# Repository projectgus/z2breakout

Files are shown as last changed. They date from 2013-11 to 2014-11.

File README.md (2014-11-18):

**This is an abandoned alpha-quality design at this point, unless someone wants to pick it up. I built some prototypes in late 2013 and the USB connector & boost converter are verified, but there's some [known problems with the connector pinout](https://github.com/projectgus/z2breakout/issues/1) and the silkscreen is also pretty messy, the whole board probably needs to grow for more labelling space.**

## Z2 Breakout module

A breakout board for the "ZipIt Z2" dock connector. Alpha-quality at the moment.

Design files created with Kicad 2013-Mar-13-testing (this version or newer is probably required.)

Breaks out dock connector to provide:
* USB A & USB Micro B connectors (only one can be used at a time.)
* Camera header for a OV7670 camera module (untested), doubles as GPIO header.
* Dedicated i2c header with 3.3V power pins
* Other breakout headers for power, onboard "headphone remote" ADC, microphone input, "BTRXD" UART pin.
* PCB contains area to build a 3.3V -> 5V boost converter based on TI TPS61240, which can be jumpered to the USB A connector. This is so the USB A connector can be used when the ZipIt is running on battery.

NB: The 3.3V power supply in the ZipIt does not contain enough capacity to output 500mA @ 5V. (If you've measured the surplus current capacity of the 3.3V supply, please let me know and I'll post it here!)

Z2 Breakout design is Copyright (C) 2013 Angus Gratton, released under the TAPR OHL as described in the included file "LICENSE".

Comes with absolutely no warranty, may not work, etc. Not endorsed by or otherwise related to the company ZipIt Wireless.

# Known Issues

* Libraries are a bit of a mess, lots of piecemeal .mod files. Due for a cleanup.

* Did I mention it hasn't been successfully made or used yet? Good. :)

# Resources

Based on the excellent research done by other Z2 owners, and the information [released by ZipIt Wireless themselves](http://linux.zipitwireless.com/):

* http://bealecorner.org/best/measure/z2/z2-connector-pinout-2011.txt

* http://embeddedprogrammer.blogspot.com.au/2012/07/hacking-ov7670-camera-module-sccb-cheat.html

If you're looking for more ZipIt Z2 hacking stuff, try:

* #zipit IRC channel on Freenode
* http://www.mozzwald.com/
* http://chainxor.org/openwrt-zipit/

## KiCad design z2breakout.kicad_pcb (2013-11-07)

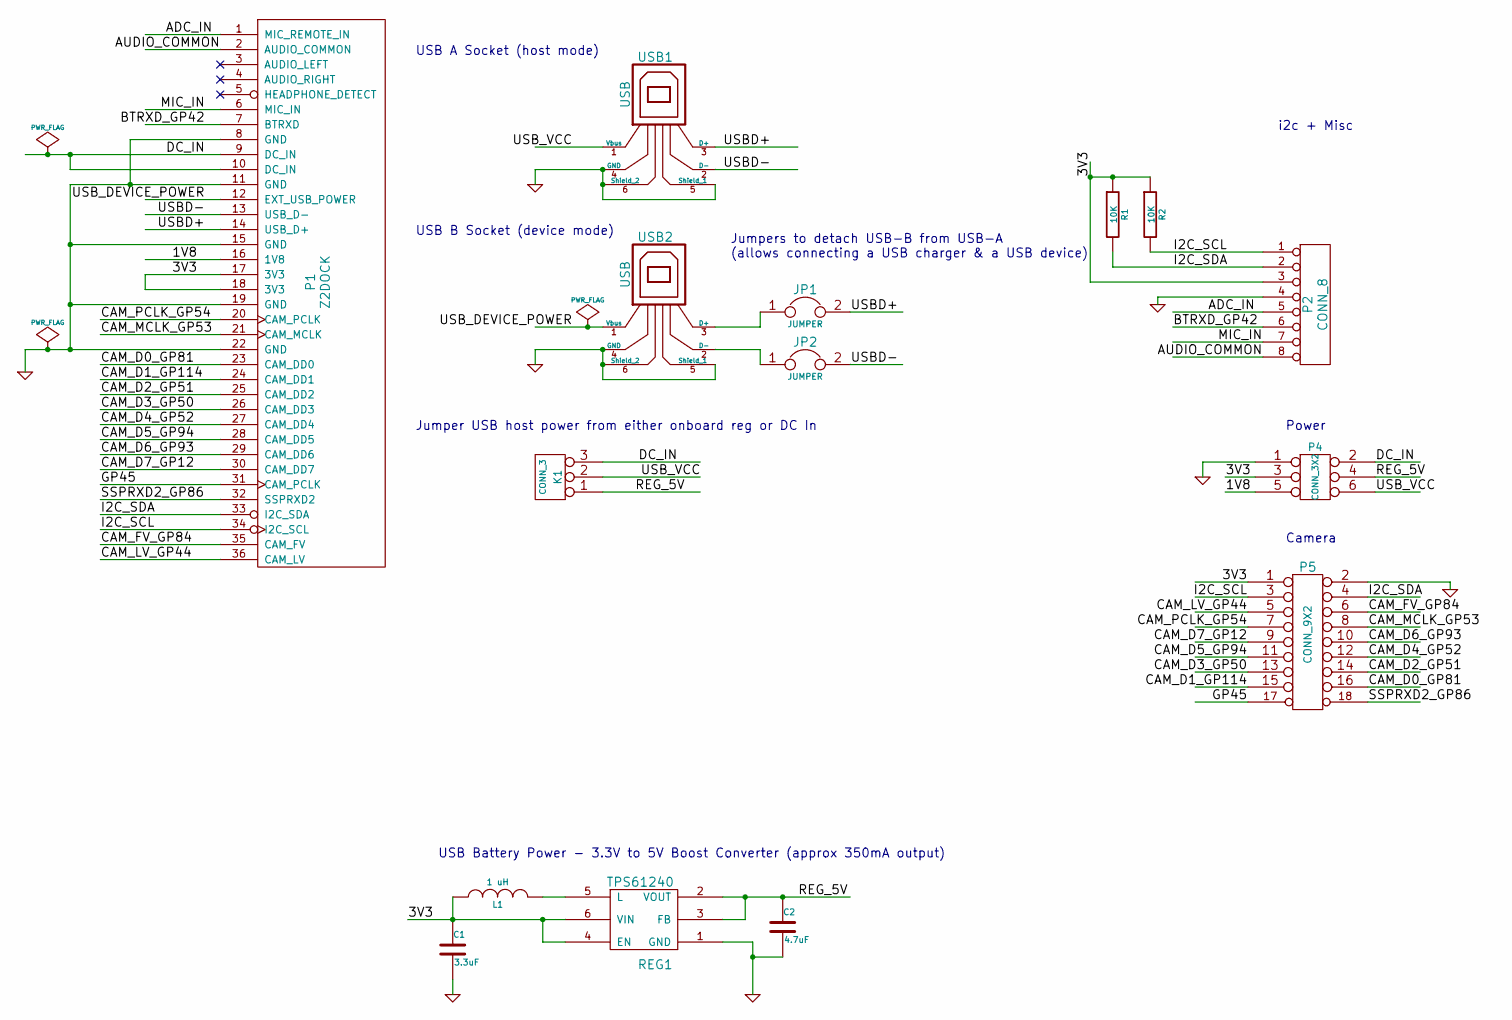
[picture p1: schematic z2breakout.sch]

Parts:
C1: 3.3uF
C2: 4.7uF
JP1, JP2: JUMPER
K1: CONN_3
L1: 1 uH
P1: Z2DOCK
P2: CONN_8
P4: CONN_3X2
P5: CONN_9X2
R1, R2: 10K
REG1: TPS61240
USB1, USB2: USB

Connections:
/1V8: P1.16 (1V8), P4.5
/3V3: C1.1, L1.1, P1.17 (3V3), P1.18 (3V3), P2.3, P4.3, P5.1, R1.1, R2.1, REG1.4 (EN), REG1.6 (VIN)
/ADC_IN: P1.1 (MIC_REMOTE_IN), P2.5
/AUDIO_COMMON: P1.2 (AUDIO_COMMON), P2.8
/BTRXD_GP42: P1.7 (BTRXD), P2.6
/CAM_D0_GP81: P1.23 (CAM_DD0), P5.16
/CAM_D1_GP114: P1.24 (CAM_DD1), P5.15
/CAM_D2_GP51: P1.25 (CAM_DD2), P5.14
/CAM_D3_GP50: P1.26 (CAM_DD3), P5.13
/CAM_D4_GP52: P1.27 (CAM_DD4), P5.12
/CAM_D5_GP94: P1.28 (CAM_DD5), P5.11
/CAM_D6_GP93: P1.29 (CAM_DD6), P5.10
/CAM_D7_GP12: P1.30 (CAM_DD7), P5.9
/CAM_FV_GP84: P1.35 (CAM_FV), P5.6
/CAM_LV_GP44: P1.36 (CAM_LV), P5.5
/CAM_MCLK_GP53: P1.21 (CAM_MCLK), P5.8
/CAM_PCLK_GP54: P1.20 (CAM_PCLK), P5.7
/DC_IN: K1.3, P1.9 (DC_IN), P1.10 (DC_IN), P4.2
/GP45: P1.31 (CAM_PCLK), P5.17
/I2C_SCL: P1.34 (I2C_SCL), P2.1, P5.3, R2.2
/I2C_SDA: P1.33 (I2C_SDA), P2.2, P5.4, R1.2
/MIC_IN: P1.6 (MIC_IN), P2.7
/REG_5V: C2.1, K1.1, P4.4, REG1.2 (VOUT), REG1.3 (FB)
/SSPRXD2_GP86: P1.32 (SSPRXD2), P5.18
/USBD+: JP1.2, P1.14 (USB_D+), USB1.3 (D+)
/USBD-: JP2.2, P1.13 (USB_D-), USB1.2 (D-)
/USB_DEVICE_POWER: P1.12 (EXT_USB_POWER), USB2.1 (Vbus)
/USB_VCC: K1.2 (PM), P4.6, USB1.1 (Vbus)
GND: C1.2, C2.2, P1.8 (GND), P1.11 (GND), P1.15 (GND), P1.19 (GND), P1.22 (GND), P2.4, P4.1, P5.2, REG1.1 (GND), USB1.4 (GND), USB1.5 (Shield_1), USB1.6 (Shield_2), USB2.4 (GND), USB2.5 (Shield_1), USB2.6 (Shield_2)
unnamed: JP1.1, USB2.3 (D+)
unnamed: JP2.1, USB2.2 (D-)
unnamed: L1.2, REG1.5 (L)

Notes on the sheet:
USB A Socket (host mode)
USB B Socket (device mode)
i2c + Misc
Power
USB Battery Power - 3.3V to 5V Boost Converter (approx 350mA output)
Camera
Jumpers to detach USB-B from USB-A (allows connecting a USB charger & a USB device)
Jumper USB host power from either onboard reg or DC In

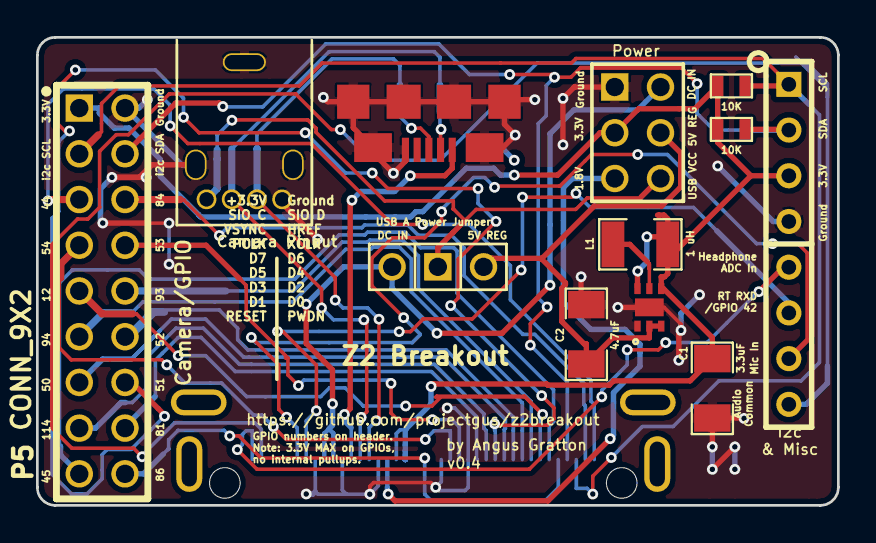
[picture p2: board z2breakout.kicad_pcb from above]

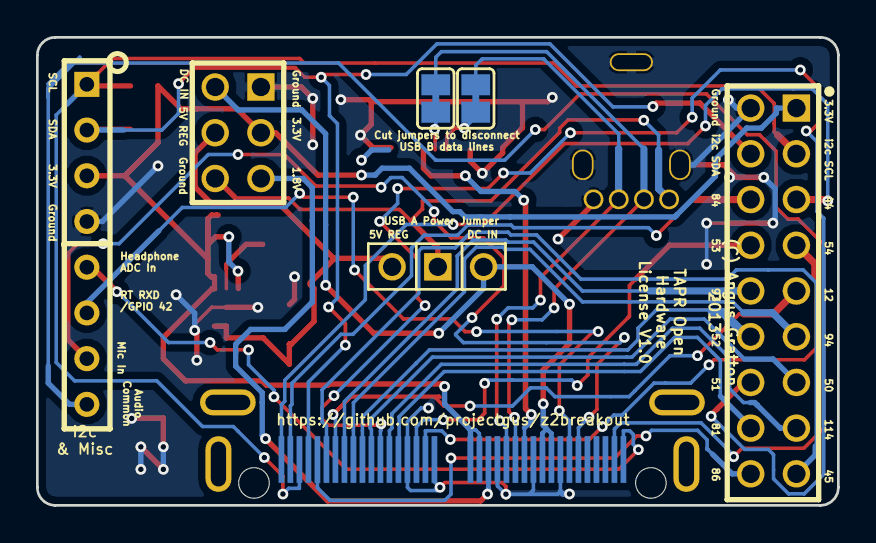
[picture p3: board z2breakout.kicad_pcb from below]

Board: 2 copper layers, 44.5 x 26.0 mm, 15 parts (3 on the bottom side), 32 nets.

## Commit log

2013-05-14 Start from previous design schematic, etc.
    [zipitbreakout.sch]
2013-06-25 Finish design, first cut of board layout for prototyping
    [zipitbreakout.kicad_pcb, zipitbreakout.sch]
2013-07-16 ST60X-36S: Fix backwards pin order, extend pads for easier hand soldering, add PCB edge/connector extent positioning lines
2013-07-16 ST60X-36S: Widen pad lands from 0.3mm to 0.32mm as per datasheet
2013-07-19 Fix footprint for upright USB A connector
2013-09-17 Reroute with correct pin order, better connector spacing
    [z2breakout.kicad_pcb, z2breakout.sch]
2013-09-18 Fix up silkscreen, try to improve grounding
    [z2breakout.kicad_pcb]
2013-11-07 Clean up silkscreen a bit, add i2c pullup resistors
    [z2breakout.kicad_pcb, z2breakout.sch]
